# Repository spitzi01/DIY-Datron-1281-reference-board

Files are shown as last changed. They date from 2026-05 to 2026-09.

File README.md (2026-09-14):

# DIY-Datron-1281-Reference-Board
Replacement board for potted reference modules in old Datron 1281

My Datron 1281 had two potted reference modules installed. One of the reference modules was jumping like crazy. So I had no other choice to remove the potting. With a heatgun at 150°C the potting become soft and can be pealed away. For me a flathead screwdriver was the right tool for the job. In my case the LTZ1000 was defective. It is necessary to save the Vishay resistor network and the hermetic op amp from the old reference board. With some passives, a new LTZ1000 and this PCB it is possible to rebuild the reference module. I tried to design the PCB as close as possible to the original. All the guarding and removed soldering mask should be there. The origial PCB has a thickness of 0.6 mm. I also designed suitable caps for the reference IC. They can be 3D printed from PETG. In my case I could also save the isolation material for the LTZ1000 from the potted module. The isolation can be reinstalled in the 3D printed caps.

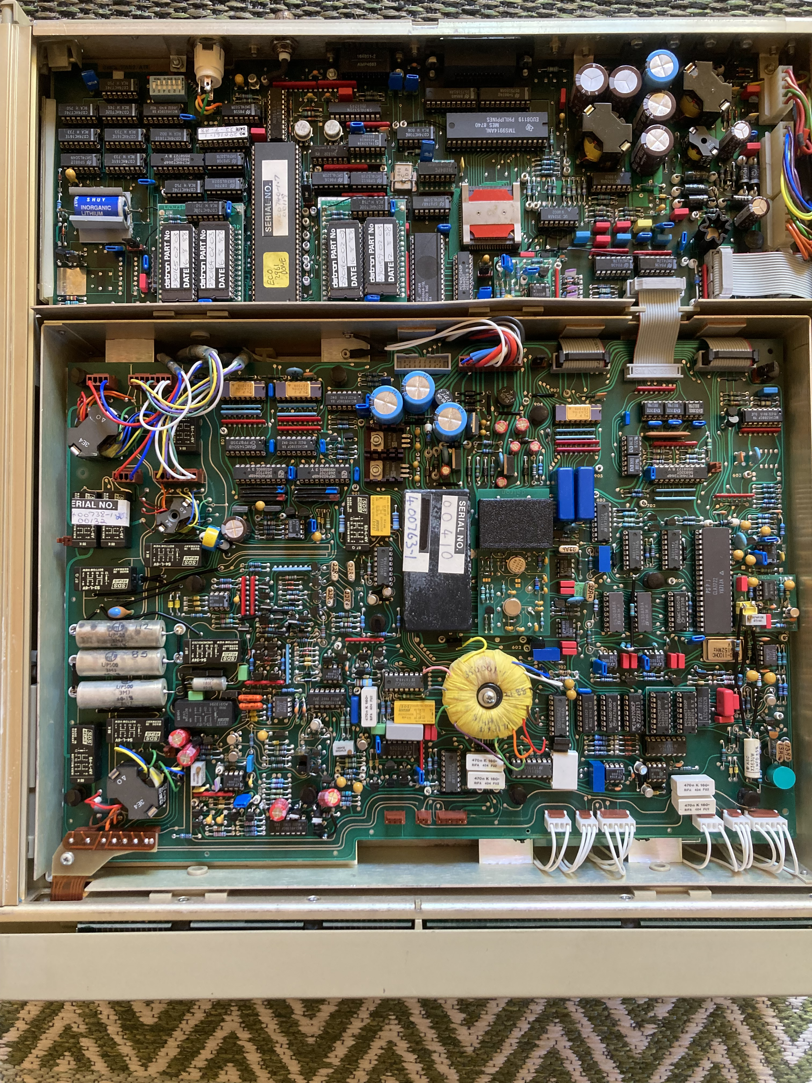
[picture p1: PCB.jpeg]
New reference pcb in Datron 1281


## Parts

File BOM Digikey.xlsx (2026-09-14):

Index | Menge | Teilenummer | Hersteller-Teilenummer | Beschreibung
1 | 3 | K223K15X7RH53L2-ND | K223K15X7RH53L2 | CAP CER 0.022UF 100V X7R RADIAL
2 | 4 | K104M20X7RH53L2-ND | K104M20X7RH53L2 | CAP CER 0.1UF 100V X7R RADIAL
3 | 1 | 56-K102K10X7RH5UL2CT-ND | K102K10X7RH5UL2 | CAP CER 1000PF 100V X7R RADIAL
4 | 1 | BC5135-ND | K103K15X7RH53L2 | CAP CER 10000PF 100V X7R RADIAL
5 | 4 | 1N4148FS-ND | 1N4148 | DIODE STANDARD 100V 200MA DO35
6 | 1 | BS170-ND | BS170 | MOSFET N-CH 60V 500MA TO92-3
7 | 2 | 13-MFR-25FTE52-150RCT-ND | MFR-25FTE52-150R | RES 150 OHM 1% 1/4W AXIAL
8 | 1 | 13-MFR-25FTE52-56KCT-ND | MFR-25FTE52-56K | RES 56K OHM 1% 1/4W AXIAL
9 | 1 | 13-MFR-25FTE52-2K7CT-ND | MFR-25FTE52-2K7 | RES 2.7K OHM 1% 1/4W AXIAL
10 | 1 | 13-MFR-25FTE52-39KCT-ND | MFR-25FTE52-39K | RES 39K OHM 1% 1/4W AXIAL
11 | 2 | 13-MFR-25FTE52-1MCT-ND | MFR-25FTE52-1M | RES 1M OHM 1% 1/4W AXIAL
12 | 1 | 13-MFR-25FTE52-150KCT-ND | MFR-25FTE52-150K | RES 150K OHM 1% 1/4W AXIAL
13 | 1 | 13-MFR-25FTE52-68KCT-ND | MFR-25FTE52-68K | RES 68K OHM 1% 1/4W AXIAL
14 | 2 | 13-MFR-25FTE52-10KCT-ND | MFR-25FTE52-10K | RES 10K OHM 1% 1/4W AXIAL

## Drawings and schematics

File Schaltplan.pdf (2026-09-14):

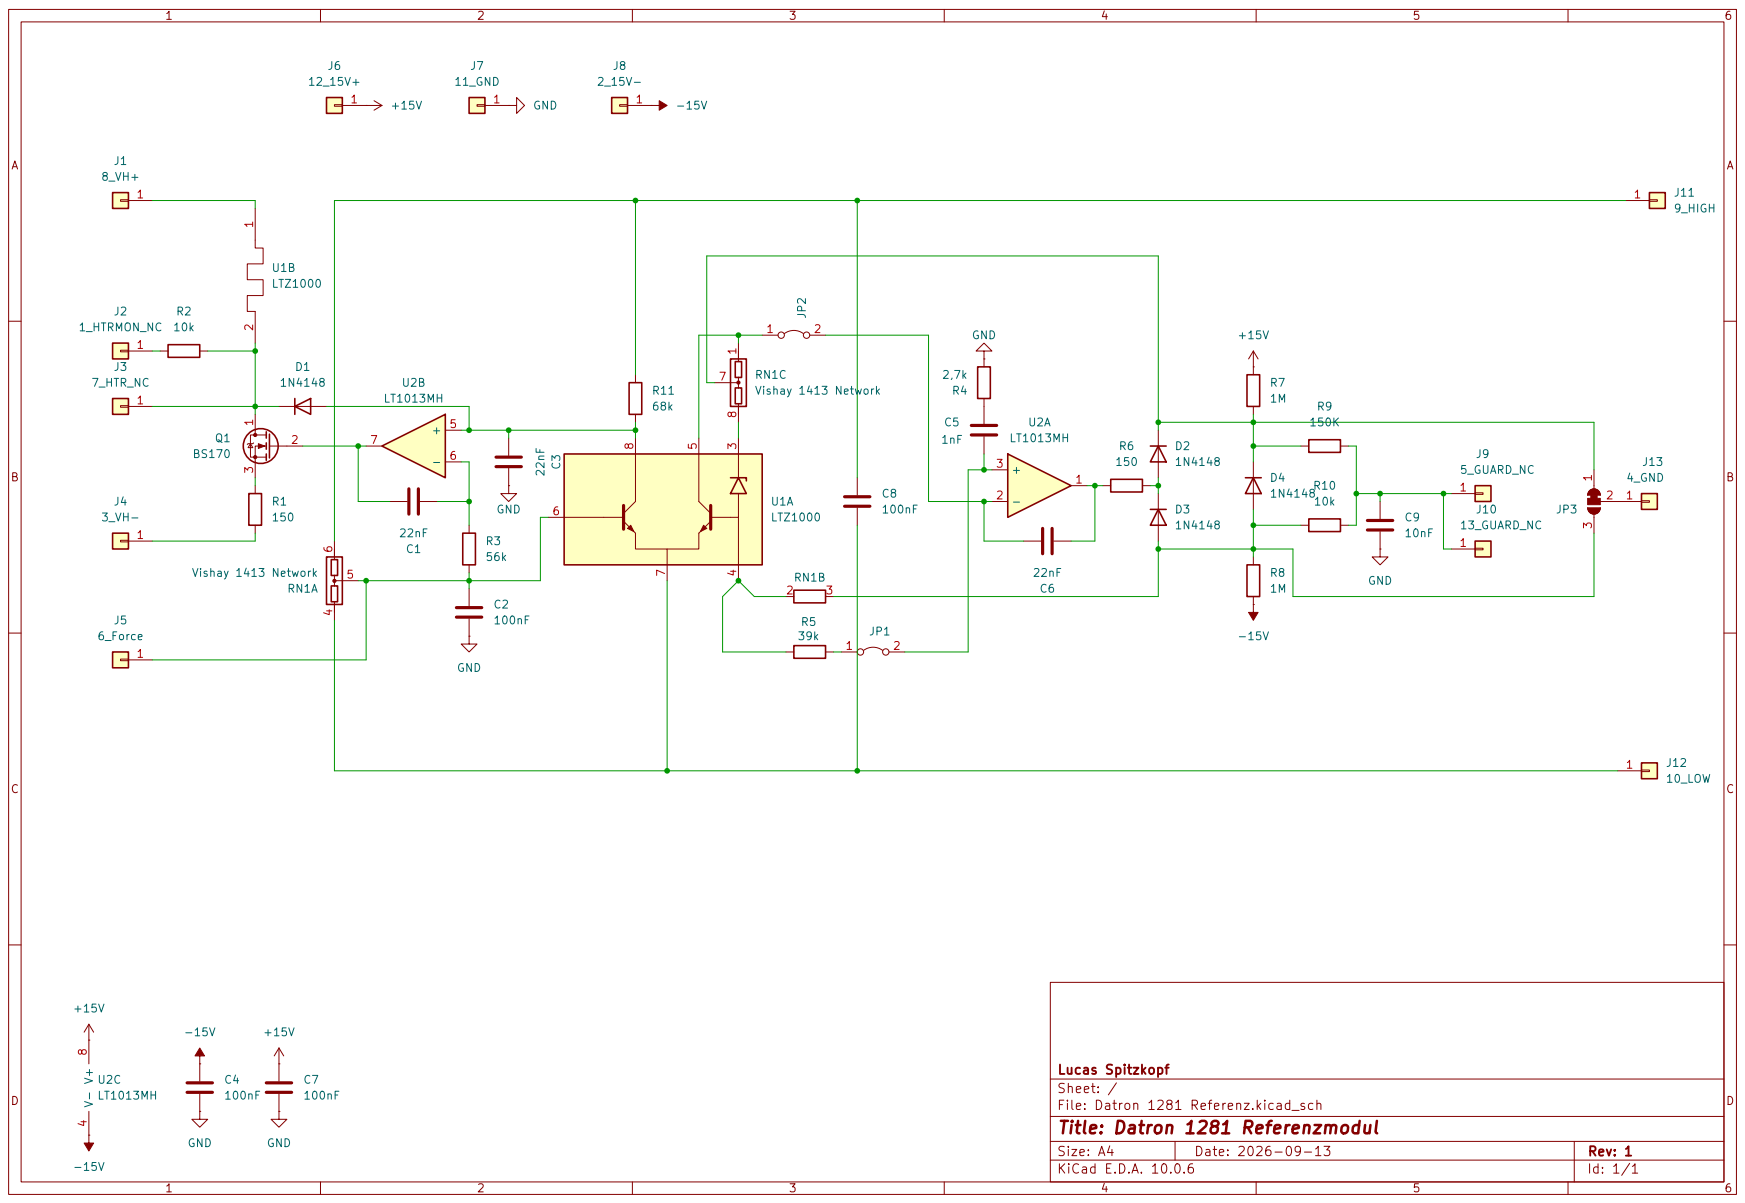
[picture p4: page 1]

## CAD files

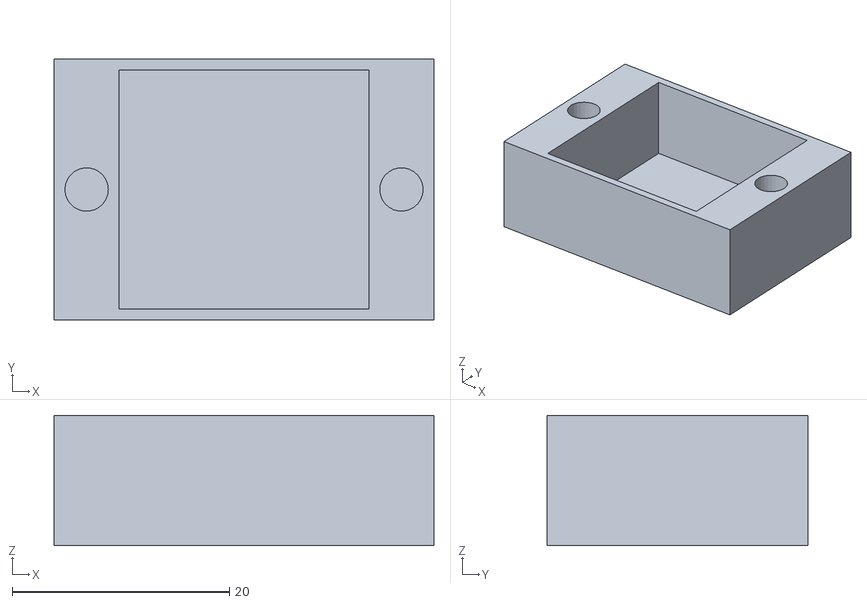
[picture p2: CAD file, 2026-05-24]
3D models/top cap.stl
35.0 x 24.0 x 12.0

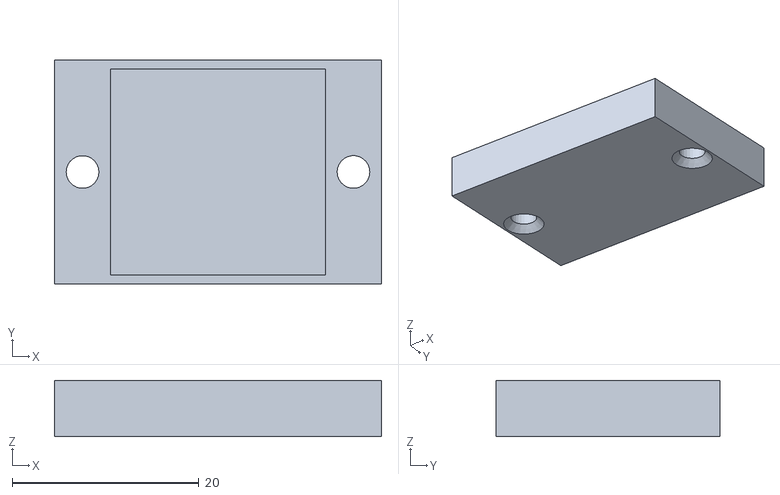
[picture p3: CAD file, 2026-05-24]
3D models/bottom cap.stl
35.0 x 24.0 x 6.00
